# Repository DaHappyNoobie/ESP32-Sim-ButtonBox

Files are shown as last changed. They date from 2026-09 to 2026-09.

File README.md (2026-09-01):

## ESP32 Sim Buttonbox
I got into flying IL-2 Great Battles pretty recently, and found myself needing a lot of buttons for control surfaces trimming, engine controls, radiators, etc...
Not enough buttons on my stick and throttle, and using keyboard is annoying! I need a button box! Good opportunity for a small personal project and learning a bit about building devices in an enclosure like this.
Time to make a simple but usable USB button box.

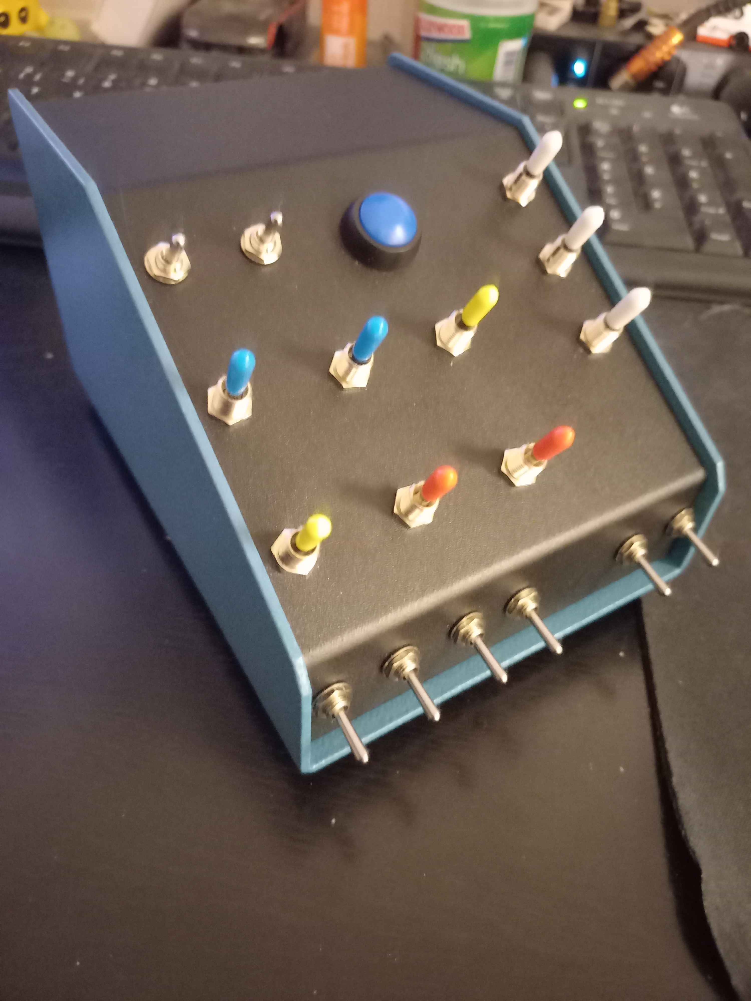
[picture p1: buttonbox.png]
Picture of the box


## What it does
This box exposes 9 bidirectional momentary switches, 8 toggle switches, and a button (27 GPIOs total). It uses an ESP32-S3 microcontroller implementing the TinyUSB stack with HID gamepad profile. This allows the box to be plug-and-play into any USB host, without the need for drivers. The circuit board and firmware are intended to be either reused as-is in other configurations, or expanded upon for more complex button boxes.

## Firmware
Written using ESP-IDF v5.5.1 framework. Install that either independently or through the VSCode extension, build,, flash, restart the board, and the USB controller should pop up in your PC's peripherals, ready to use.
The firmware itself is simple, derived from the TinyUSb HID example in ESP-IDF. A simple polling loop handles reading all the inputs, then building and sending a HID report through USB. Provisions are made in hardware to use the I/Os in Interrupt mode instead of polling (even through the I²C GPIO expander), but it's not really needed for my current use.
Keep the small Boot button pressed on the board while plugging the USB in to boot up in firmware download mode and reprogram the board if needed.

## Hardware
I designed a small 2-layer PCB implementing everything that's needed for a generic button box controller. Hook up your buttons and switches to the screw terminals on the board and start building.
The USB-B receptacle sticks out the back of the PCB, as it is intended to be mounted against the rear face of the enclosure.
I used a Hammond 1456CE3BKBU aluminium enclosure to build this project. It's relatively cheap, easy to work on, and has the perfect form factor for my space-constrained requirements.

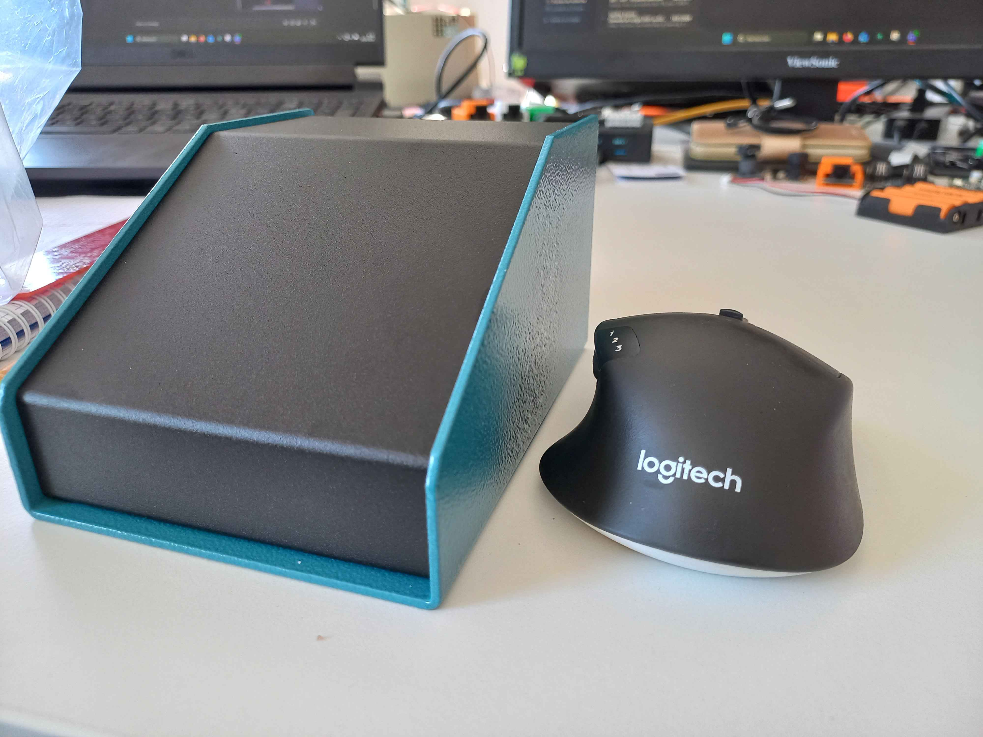
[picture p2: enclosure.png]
Bare enclosure

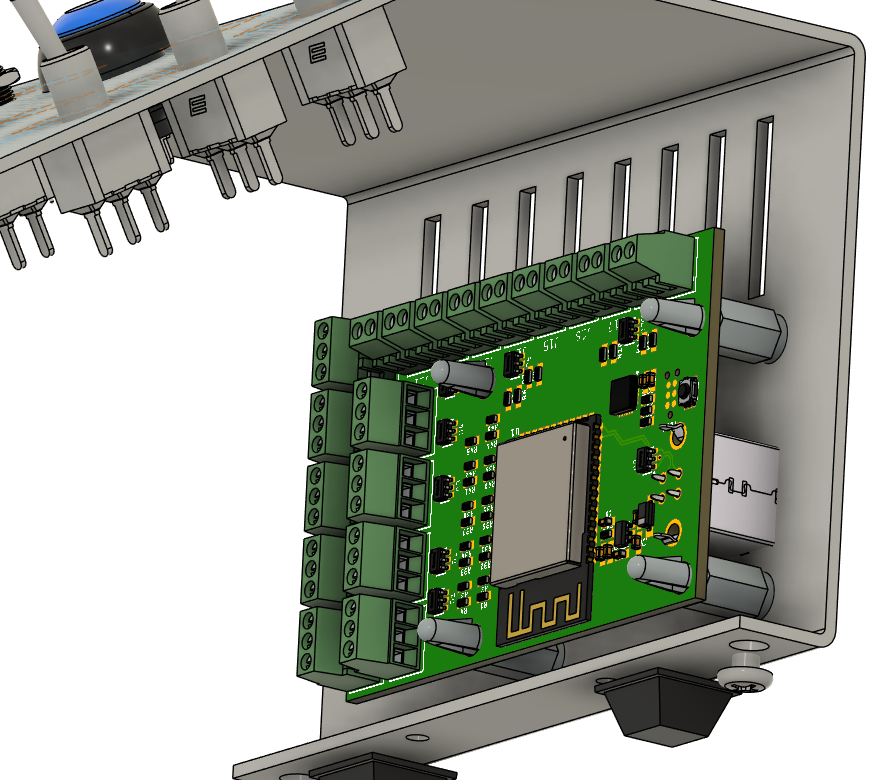
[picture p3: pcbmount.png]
PCB mount


MECHANICAL_ASSEMBLY folder contains 3D models in.step format for the following elements :
- Bare enclosure as sold
- Enclosure with the necessary drill holes for buttons, switches and mounting
- Controller circuit board
- Fully assembled button box (with all independent parts embedded in the file)

PCB_ESP32_SimButtonBox folder contains the circuit board design files :
- Parts BOM
- Autodesk EAGLE CAD files in .sch and .brd formats. Since EAGLE is now discontinued, you should be able to import them in Fusion360 Electronics with no issue. KiCAD should work too!
- Schematic in PDF format
- Gerber files for manufacturing the PCBs. I recommend getting a small solder stencil according to the Gerbers for easier reflow soldering.

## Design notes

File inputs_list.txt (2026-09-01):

List of button box inputs
-------------------------

Total : 
9 Momentary switches
8 Toggle switches
1 Buttons
-----> If using 9 momentaries, 8 toggles, 1 button -> 27 GPIOs
-----> At least 1 GPIO Expander (16bit) should be used

TRIMMING
--------
Elevator Trim / Stabilizer +/- -> Momentary switch
Aileron Trim +/- -> Momentary switch
Rudder Trim +/- -> Momentary switch

ENGINE CONTROL
--------------
Engine Select 1 On/Off -> Toggle switch (small)
Engine Select 2 On/Off -> Toggle switch (small)
Propeller Pitch / RPM +/- -> Momentary switch
Fuel Mixture +/- -> Momentary switch
Oil Radiator +/- -> Momentary switch
Water Radiator / Inlet cowl +/- -> Momentary switch
Outlet cowl +/- -> Momentary switch
Supercharger Gear +/- -> Momentary switch
Engine Ignition -> Button

GEAR AND LIGHTS
---------------
Landing Gear Up/Down -> Toggle switch
Tail Wheel Lock/Unlock -> Toggle switch
Landing Lights toggle -> Toggle switch
Formation Lights toggle -> Toggle switch

MISC
----
Bomber autopilot/autolevel -> Toggle switch

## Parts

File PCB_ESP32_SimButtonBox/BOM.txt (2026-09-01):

Partlist exported from C:/Users/HugoCuzon/Documents/Perso-3D/ESP32_SimButtonBox/ESP32_SimButtonBox_Controller.sch at 18/02/2026 12:15

Qty Value               Device                   Package                   Parts                                                                                                                                  Description                                               ALTERNATE APPLICATION BOM_CAT C-CH CHANNELS CROSS-REF CROSSREFS CURRENT DATASHEET-URL                                                 DESCRIPTION                                                               EQUIVALENCE GERDER     H     INTERFACE-TYPE IOUT  IPEAK IR-UL IR1  ISHDN MATERIAL MF                MOUNT MP                  NOT_IN_BOM OPERATION-FORCE PACKAGING PINS PITCH  POL POPULARITY POWER REF-EXCALIBUR REF_EXCALIBUR TOLERANCE TYPE       VALUE         VBR VMAX VMIN  VOLTAGE WIRE                                 WORKING-VOLTAGE WORKING-VOLTAGE-UL
9                       691210910002             691210910002              J11, J12, J13, J14, J15, J16, J17, J18, J19                                                                                            WR-TBL Serie 2109 - 2.54 mm Horiz. Entry                                                                                          https://www.we-online.com/catalog/datasheet/691210910002.pdf  WR-TBL Rising Cage Clamp                                                                                                          6A                        Wurth Elektronik  THT    691210910002                                             2   2.54mm                                                            Horizontal                                      30 to 18 (AWG) 0.0509 to 0.823 (mm²)                 150V (AC)         
9                       691210910003             691210910003              J2, J3, J4, J5, J6, J7, J8, J9, J10                                                                                                    WR-TBL Serie 2109 - 2.54 mm Horiz. Entry                                                                                          https://www.we-online.com/catalog/datasheet/691210910003.pdf  WR-TBL Rising Cage Clamp                                                                                                          6A                        Wurth Elektronik  THT    691210910003                                             3   2.54mm                                                            Horizontal                                      30 to 18 (AWG) 0.0509 to 0.823 (mm²)                 150V (AC)         
3   100nF               CAP_0603                 C0603                     C4, C7, C8                                                                                                                             Capacitor                                                                       C_SMD                                                                                                                                                                                                                                                              X5R/X7R                                                                                                                                                                                                  16V                                                                            
29  10k                 RES_0603                 R0603                     R1, R2, R3, R4, R5, R6, R7, R8, R9, R10, R11, R12, R13, R30, R31, R32, R33, R34, R35, R36, R37, R38, R39, R40, R41, R42, R43, R44, R45 Resistor                                                                        R_SMD                                                                                                                                                                                                                                                                                                                                                                        80                                           1%                                                                                                                               
1   1N5819HW            SCHOTTKY_SOD123          SOD123                    D9                                                                                                                                     Schottky Diode                                                                                                            1A                                                                    Schottky diode                                                                                                                                                                      1N5819HW                                                                                                                                                                                                                                               
4   1uF                 CAP_0603                 C0603                     C1, C2, C3, C6                                                                                                                         Capacitor                                                                       C_SMD                                                                                                                                                                                                                                                              X5R/X7R                                                                                                                                                                                                  16V                                                                            
2   4.7k                RES_0603                 R0603                     R28, R29                                                                                                                               Resistor                                                                        R_SMD                                                                                                                                                                                                                                                                                                                                                                        80                                           1%                                                                                                                               
1   435151014824        435151014824             435151014824              S1                                                                                                                                     WS-TASV SMT Tact Switch 3.0 x 2.6 mm with ground terminal                                                                         https://www.we-online.com/catalog/datasheet/435151014824 .pdf WS-TASV Switches - Tact Switches                                                                 1.4mm                                                      Wurth Elektronik        435151014824                   240g                                                                                                        435151014824                                                                                                
8   5Vdc                WE-TVS_SOT23-6L_82402304 WE-TVS_SOT23-6L           D1, D2, D3, D4, D5, D6, D7, D8                                                                                                         WE-TVS TVS Diode – Standard Series                                                      13pF  4                                   https://www.we-online.com/catalog/datasheet/82402304.pdf      WE-TVS TVS Diode                                                                                                            6A                              Wurth Elektronik  SMT   82402304                                                                                                                                   5Vdc          6V                                                                                            
1   61400413321         61400413321              61400413321               J1                                                                                                                                     WR-COM USB 2.0 Type B Vertical                                      USB 2.0                                                       https://www.we-online.com/catalog/datasheet/61400413321.pdf   WR-USB Input/Output USB connectors                                                    Receptacle       Type B                           1.5A                Wurth Elktronik   THT   61400413321                                    Tray       4                               03178                                 Vertical   61400413321                                                               30V(AC)                           
1   ESP32-S3-WROOM-1-N8 ESP32-S3-WROOM-1-N8      WROOM-1                   U1                                                                                                                                     Module Overview                                                                                                                                                                                 Modules multiprotocoles SMD Module, ESP32-S3, 8 MB SPI Flash, PCB Antenna                                                                                   Espressif Systems       ESP32-S3-WROOM-1-N8                                                                                                                                                                                                                                    
1   LDO_EN_SOT23-5      LDO_EN_SOT23-5           SOT23-5                   U2                                                                                                                                     LDO with Enable pin                                                                                                                                                                             LDO                                                                                                                   500mA                                 Texas Instruments       TLV75533PDBV*                                                                                                                                                5.5V 1.45V                                                                                
1   PCF8575RGE          PCF8575RGE               QFN50P400X400X100-25T210N U3                                                                                                                                     Texas Instruments PCF8575                                                                                                                                                                       16bit I2C IO Expander                                                                                                                                       Texas Instruments       PCF8575RGER                                                                                                                                                                                                                                            
1   TC2030-MCP-NL       TC2030-MCP-NL            TC2030-MCP-NL             TCB1                                                                                                                                   TAG-CONNECT ICSP Connector                                                                                                                                                                                                                                                                                                                                                                              true                                                                                                                                                                                                                               
1   dnm                 CAP_0603                 C0603                     C5                                                                                                                                     Capacitor                                                                       C_SMD                                                                                                                                                                                                                                                              X5R/X7R                                                                                                                                                                                                  16V

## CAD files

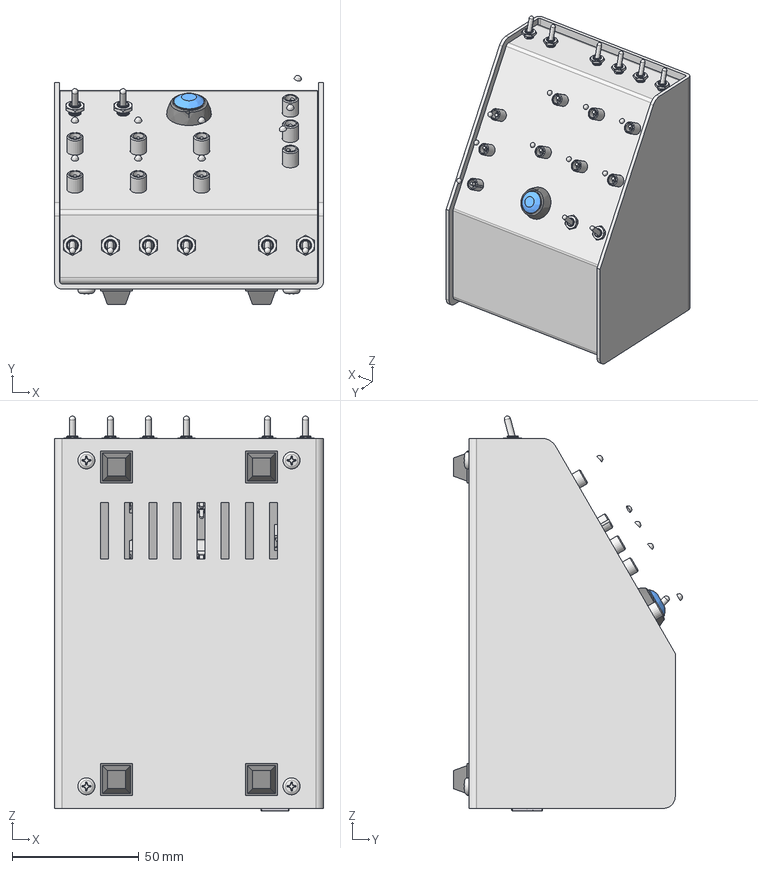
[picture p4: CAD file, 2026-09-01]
MECHANICAL_ASSEMBLY/ASSEMBLED_Buttonbox.step
106.2 x 90.4 x 155.8 mm
Taiway sub miniature switch spdt x 8
1456CE3 CASE
3M SJ-5018 RUBBER FOOT (PFR1421T3) x 4
Board
TC2030-MCP-NL
SOT23-5
C0201_20210301.STEP^C0201_20210301.STEP_Submodel-C0201_part_DesignRoo tModel_PCB_ESP32-S3-WROOM-1_V1(2)_PCB_ESP32-S3-WROOM-1_V1 x 14
L0201_20210301.STEP^L0201_20210301.STEP_Submodel-L0201_part_DesignRoo tModel_PCB_ESP32-S3-WROOM-1_V1(2)_PCB_ESP32-S3-WROOM-1_V1 x 3
C0402_20210301.STEP^C0402_20210301.STEP_Submodel-C0402_part_DesignRoo tModel_PCB_ESP32-S3-WROOM-1_V1(2)_PCB_ESP32-S3-WROOM-1_V1
R0201_20210301.STEP^R0201_20210301.STEP_Submodel-R0201_part_DesignRoo tModel_PCB_ESP32-S3-WROOM-1_V1(2)_PCB_ESP32-S3-WROOM-1_V1 x 8
trace_1^Submodel-MINI-ANT-TYPEB_668419613_part_DesignRootModel_PCB_ES P32-S3-WROOM-1_V1(2)_PCB_ESP32-S3-WROOM-1_V1
DFN1006.STEP^DFN1006.STEP_Submodel-SOD882_part_DesignRootModel_PCB_ES P32-S3-WROOM-1_V1(2)_PCB_ESP32-S3-WROOM-1_V1
SOP8_rev1_20210308.STEP^SOP8_rev1_20210308.STEP_Submodel-SOP8_1P27_6P 6_part_DesignRootModel_PCB_ESP32-S3-WROOM-1_V1(2)_PCB_ESP32-S3-WROOM-1 _V1
XTAL3225_20210301.STEP^XTAL3225_20210301.STEP_Submodel-XTAL3225_part_ DesignRootModel_PCB_ESP32-S3-WROOM-1_V1(2)_PCB_ESP32-S3-WROOM-1_V1
ESP32-S3_20210301.STEP^ESP32-S3_20210301.STEP_Submodel-QFN56_0P4_7_pa rt_DesignRootModel_PCB_ESP32-S3-WROOM-1_V1(2)_PCB_ESP32-S3-WROOM-1_V1
uid__4-128^DesignRootModel_PCB_ESP32-S3-WROOM-1_V1(2)_PCB_ESP32-S3-WR OOM-1_V1
uid__4-129^DesignRootModel_PCB_ESP32-S3-WROOM-1_V1(2)_PCB_ESP32-S3-WR OOM-1_V1
uid__4-130^DesignRootModel_PCB_ESP32-S3-WROOM-1_V1(2)_PCB_ESP32-S3-WR OOM-1_V1
uid__4-149^DesignRootModel_PCB_ESP32-S3-WROOM-1_V1(2)_PCB_ESP32-S3-WR OOM-1_V1
uid__4-150^DesignRootModel_PCB_ESP32-S3-WROOM-1_V1(2)_PCB_ESP32-S3-WR OOM-1_V1
uid__4-151^DesignRootModel_PCB_ESP32-S3-WROOM-1_V1(2)_PCB_ESP32-S3-WR OOM-1_V1
uid__4-167^DesignRootModel_PCB_ESP32-S3-WROOM-1_V1(2)_PCB_ESP32-S3-WR OOM-1_V1
uid__4-168^DesignRootModel_PCB_ESP32-S3-WROOM-1_V1(2)_PCB_ESP32-S3-WR OOM-1_V1
uid__4-169^DesignRootModel_PCB_ESP32-S3-WROOM-1_V1(2)_PCB_ESP32-S3-WR OOM-1_V1
uid__1-279^DesignRootModel_PCB_ESP32-S3-WROOM-1_V1(2)_PCB_ESP32-S3-WR OOM-1_V1
uid__1-280^DesignRootModel_PCB_ESP32-S3-WROOM-1_V1(2)_PCB_ESP32-S3-WR OOM-1_V1
uid__1-292^DesignRootModel_PCB_ESP32-S3-WROOM-1_V1(2)_PCB_ESP32-S3-WR OOM-1_V1
uid__1-298^DesignRootModel_PCB_ESP32-S3-WROOM-1_V1(2)_PCB_ESP32-S3-WR OOM-1_V1
uid__1-299^DesignRootModel_PCB_ESP32-S3-WROOM-1_V1(2)_PCB_ESP32-S3-WR OOM-1_V1
uid__1-300^DesignRootModel_PCB_ESP32-S3-WROOM-1_V1(2)_PCB_ESP32-S3-WR OOM-1_V1
uid__1-301^DesignRootModel_PCB_ESP32-S3-WROOM-1_V1(2)_PCB_ESP32-S3-WR OOM-1_V1
uid__1-304^DesignRootModel_PCB_ESP32-S3-WROOM-1_V1(2)_PCB_ESP32-S3-WR OOM-1_V1
uid__1-305^DesignRootModel_PCB_ESP32-S3-WROOM-1_V1(2)_PCB_ESP32-S3-WR OOM-1_V1
uid__1-308^DesignRootModel_PCB_ESP32-S3-WROOM-1_V1(2)_PCB_ESP32-S3-WR OOM-1_V1
uid__1-310^DesignRootModel_PCB_ESP32-S3-WROOM-1_V1(2)_PCB_ESP32-S3-WR OOM-1_V1
uid__1-311^DesignRootModel_PCB_ESP32-S3-WROOM-1_V1(2)_PCB_ESP32-S3-WR OOM-1_V1
uid__1-325^DesignRootModel_PCB_ESP32-S3-WROOM-1_V1(2)_PCB_ESP32-S3-WR OOM-1_V1
uid__1-334^DesignRootModel_PCB_ESP32-S3-WROOM-1_V1(2)_PCB_ESP32-S3-WR OOM-1_V1
uid__1-338^DesignRootModel_PCB_ESP32-S3-WROOM-1_V1(2)_PCB_ESP32-S3-WR OOM-1_V1
uid__1-339^DesignRootModel_PCB_ESP32-S3-WROOM-1_V1(2)_PCB_ESP32-S3-WR OOM-1_V1
uid__1-340^DesignRootModel_PCB_ESP32-S3-WROOM-1_V1(2)_PCB_ESP32-S3-WR OOM-1_V1
uid__1-343^DesignRootModel_PCB_ESP32-S3-WROOM-1_V1(2)_PCB_ESP32-S3-WR OOM-1_V1
uid__1-344^DesignRootModel_PCB_ESP32-S3-WROOM-1_V1(2)_PCB_ESP32-S3-WR OOM-1_V1
uid__1-345^DesignRootModel_PCB_ESP32-S3-WROOM-1_V1(2)_PCB_ESP32-S3-WR OOM-1_V1
uid__1-352^DesignRootModel_PCB_ESP32-S3-WROOM-1_V1(2)_PCB_ESP32-S3-WR OOM-1_V1
uid__1-354^DesignRootModel_PCB_ESP32-S3-WROOM-1_V1(2)_PCB_ESP32-S3-WR OOM-1_V1
uid__1-355^DesignRootModel_PCB_ESP32-S3-WROOM-1_V1(2)_PCB_ESP32-S3-WR OOM-1_V1
uid__1-357^DesignRootModel_PCB_ESP32-S3-WROOM-1_V1(2)_PCB_ESP32-S3-WR OOM-1_V1
uid__1-358^DesignRootModel_PCB_ESP32-S3-WROOM-1_V1(2)_PCB_ESP32-S3-WR OOM-1_V1
uid__1-359^DesignRootModel_PCB_ESP32-S3-WROOM-1_V1(2)_PCB_ESP32-S3-WR OOM-1_V1
uid__1-364^DesignRootModel_PCB_ESP32-S3-WROOM-1_V1(2)_PCB_ESP32-S3-WR OOM-1_V1
uid__1-365^DesignRootModel_PCB_ESP32-S3-WROOM-1_V1(2)_PCB_ESP32-S3-WR OOM-1_V1
uid__1-371^DesignRootModel_PCB_ESP32-S3-WROOM-1_V1(2)_PCB_ESP32-S3-WR OOM-1_V1
uid__1-375^DesignRootModel_PCB_ESP32-S3-WROOM-1_V1(2)_PCB_ESP32-S3-WR OOM-1_V1
uid__1-376^DesignRootModel_PCB_ESP32-S3-WROOM-1_V1(2)_PCB_ESP32-S3-WR OOM-1_V1
uid__1-378^DesignRootModel_PCB_ESP32-S3-WROOM-1_V1(2)_PCB_ESP32-S3-WR OOM-1_V1
uid__1-379^DesignRootModel_PCB_ESP32-S3-WROOM-1_V1(2)_PCB_ESP32-S3-WR OOM-1_V1
uid__1-380^DesignRootModel_PCB_ESP32-S3-WROOM-1_V1(2)_PCB_ESP32-S3-WR OOM-1_V1
uid__1-381^DesignRootModel_PCB_ESP32-S3-WROOM-1_V1(2)_PCB_ESP32-S3-WR OOM-1_V1
uid__1-382^DesignRootModel_PCB_ESP32-S3-WROOM-1_V1(2)_PCB_ESP32-S3-WR OOM-1_V1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

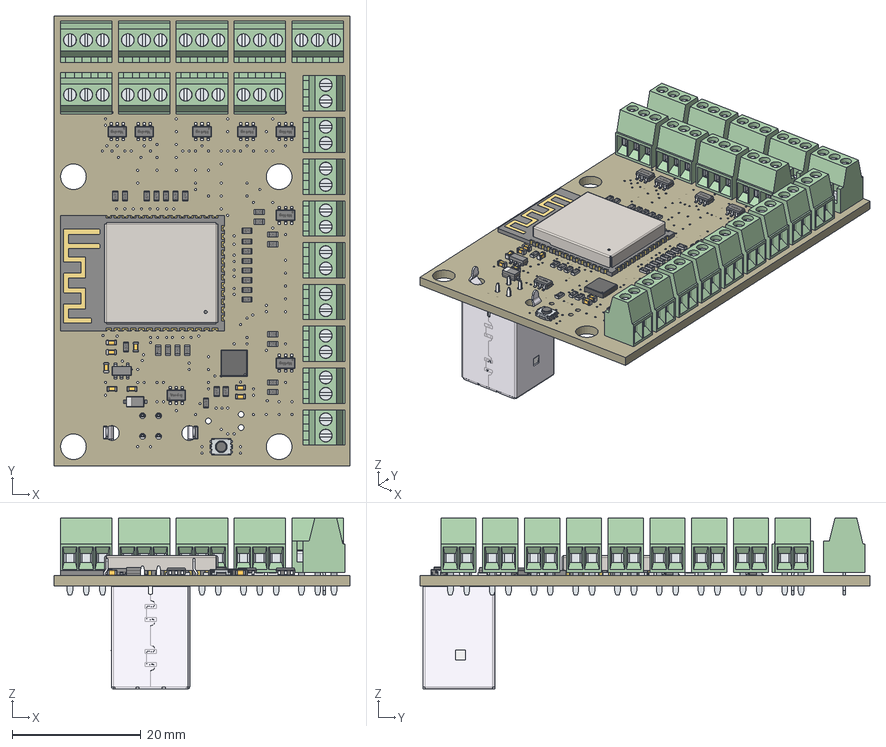
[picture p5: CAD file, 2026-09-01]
MECHANICAL_ASSEMBLY/3DPCB_ESP32_SimButtonBox_Controller.step
46.0 x 70.0 x 26.6 mm
Board
TC2030-MCP-NL
SOT23-5
C0201_20210301.STEP^C0201_20210301.STEP_Submodel-C0201_part_DesignRoo tModel_PCB_ESP32-S3-WROOM-1_V1(2)_PCB_ESP32-S3-WROOM-1_V1 x 14
L0201_20210301.STEP^L0201_20210301.STEP_Submodel-L0201_part_DesignRoo tModel_PCB_ESP32-S3-WROOM-1_V1(2)_PCB_ESP32-S3-WROOM-1_V1 x 3
C0402_20210301.STEP^C0402_20210301.STEP_Submodel-C0402_part_DesignRoo tModel_PCB_ESP32-S3-WROOM-1_V1(2)_PCB_ESP32-S3-WROOM-1_V1
R0201_20210301.STEP^R0201_20210301.STEP_Submodel-R0201_part_DesignRoo tModel_PCB_ESP32-S3-WROOM-1_V1(2)_PCB_ESP32-S3-WROOM-1_V1 x 8
trace_1^Submodel-MINI-ANT-TYPEB_668419613_part_DesignRootModel_PCB_ES P32-S3-WROOM-1_V1(2)_PCB_ESP32-S3-WROOM-1_V1
DFN1006.STEP^DFN1006.STEP_Submodel-SOD882_part_DesignRootModel_PCB_ES P32-S3-WROOM-1_V1(2)_PCB_ESP32-S3-WROOM-1_V1
SOP8_rev1_20210308.STEP^SOP8_rev1_20210308.STEP_Submodel-SOP8_1P27_6P 6_part_DesignRootModel_PCB_ESP32-S3-WROOM-1_V1(2)_PCB_ESP32-S3-WROOM-1 _V1
XTAL3225_20210301.STEP^XTAL3225_20210301.STEP_Submodel-XTAL3225_part_ DesignRootModel_PCB_ESP32-S3-WROOM-1_V1(2)_PCB_ESP32-S3-WROOM-1_V1
ESP32-S3_20210301.STEP^ESP32-S3_20210301.STEP_Submodel-QFN56_0P4_7_pa rt_DesignRootModel_PCB_ESP32-S3-WROOM-1_V1(2)_PCB_ESP32-S3-WROOM-1_V1
uid__4-128^DesignRootModel_PCB_ESP32-S3-WROOM-1_V1(2)_PCB_ESP32-S3-WR OOM-1_V1
uid__4-129^DesignRootModel_PCB_ESP32-S3-WROOM-1_V1(2)_PCB_ESP32-S3-WR OOM-1_V1
uid__4-130^DesignRootModel_PCB_ESP32-S3-WROOM-1_V1(2)_PCB_ESP32-S3-WR OOM-1_V1
uid__4-149^DesignRootModel_PCB_ESP32-S3-WROOM-1_V1(2)_PCB_ESP32-S3-WR OOM-1_V1
uid__4-150^DesignRootModel_PCB_ESP32-S3-WROOM-1_V1(2)_PCB_ESP32-S3-WR OOM-1_V1
uid__4-151^DesignRootModel_PCB_ESP32-S3-WROOM-1_V1(2)_PCB_ESP32-S3-WR OOM-1_V1
uid__4-167^DesignRootModel_PCB_ESP32-S3-WROOM-1_V1(2)_PCB_ESP32-S3-WR OOM-1_V1
uid__4-168^DesignRootModel_PCB_ESP32-S3-WROOM-1_V1(2)_PCB_ESP32-S3-WR OOM-1_V1
uid__4-169^DesignRootModel_PCB_ESP32-S3-WROOM-1_V1(2)_PCB_ESP32-S3-WR OOM-1_V1
uid__1-279^DesignRootModel_PCB_ESP32-S3-WROOM-1_V1(2)_PCB_ESP32-S3-WR OOM-1_V1
uid__1-280^DesignRootModel_PCB_ESP32-S3-WROOM-1_V1(2)_PCB_ESP32-S3-WR OOM-1_V1
uid__1-292^DesignRootModel_PCB_ESP32-S3-WROOM-1_V1(2)_PCB_ESP32-S3-WR OOM-1_V1
uid__1-298^DesignRootModel_PCB_ESP32-S3-WROOM-1_V1(2)_PCB_ESP32-S3-WR OOM-1_V1
uid__1-299^DesignRootModel_PCB_ESP32-S3-WROOM-1_V1(2)_PCB_ESP32-S3-WR OOM-1_V1
uid__1-300^DesignRootModel_PCB_ESP32-S3-WROOM-1_V1(2)_PCB_ESP32-S3-WR OOM-1_V1
uid__1-301^DesignRootModel_PCB_ESP32-S3-WROOM-1_V1(2)_PCB_ESP32-S3-WR OOM-1_V1
uid__1-304^DesignRootModel_PCB_ESP32-S3-WROOM-1_V1(2)_PCB_ESP32-S3-WR OOM-1_V1
uid__1-305^DesignRootModel_PCB_ESP32-S3-WROOM-1_V1(2)_PCB_ESP32-S3-WR OOM-1_V1
uid__1-308^DesignRootModel_PCB_ESP32-S3-WROOM-1_V1(2)_PCB_ESP32-S3-WR OOM-1_V1
uid__1-310^DesignRootModel_PCB_ESP32-S3-WROOM-1_V1(2)_PCB_ESP32-S3-WR OOM-1_V1
uid__1-311^DesignRootModel_PCB_ESP32-S3-WROOM-1_V1(2)_PCB_ESP32-S3-WR OOM-1_V1
uid__1-325^DesignRootModel_PCB_ESP32-S3-WROOM-1_V1(2)_PCB_ESP32-S3-WR OOM-1_V1
uid__1-334^DesignRootModel_PCB_ESP32-S3-WROOM-1_V1(2)_PCB_ESP32-S3-WR OOM-1_V1
uid__1-338^DesignRootModel_PCB_ESP32-S3-WROOM-1_V1(2)_PCB_ESP32-S3-WR OOM-1_V1
uid__1-339^DesignRootModel_PCB_ESP32-S3-WROOM-1_V1(2)_PCB_ESP32-S3-WR OOM-1_V1
uid__1-340^DesignRootModel_PCB_ESP32-S3-WROOM-1_V1(2)_PCB_ESP32-S3-WR OOM-1_V1
uid__1-343^DesignRootModel_PCB_ESP32-S3-WROOM-1_V1(2)_PCB_ESP32-S3-WR OOM-1_V1
uid__1-344^DesignRootModel_PCB_ESP32-S3-WROOM-1_V1(2)_PCB_ESP32-S3-WR OOM-1_V1
uid__1-345^DesignRootModel_PCB_ESP32-S3-WROOM-1_V1(2)_PCB_ESP32-S3-WR OOM-1_V1
uid__1-352^DesignRootModel_PCB_ESP32-S3-WROOM-1_V1(2)_PCB_ESP32-S3-WR OOM-1_V1
uid__1-354^DesignRootModel_PCB_ESP32-S3-WROOM-1_V1(2)_PCB_ESP32-S3-WR OOM-1_V1
uid__1-355^DesignRootModel_PCB_ESP32-S3-WROOM-1_V1(2)_PCB_ESP32-S3-WR OOM-1_V1
uid__1-357^DesignRootModel_PCB_ESP32-S3-WROOM-1_V1(2)_PCB_ESP32-S3-WR OOM-1_V1
uid__1-358^DesignRootModel_PCB_ESP32-S3-WROOM-1_V1(2)_PCB_ESP32-S3-WR OOM-1_V1
uid__1-359^DesignRootModel_PCB_ESP32-S3-WROOM-1_V1(2)_PCB_ESP32-S3-WR OOM-1_V1
uid__1-364^DesignRootModel_PCB_ESP32-S3-WROOM-1_V1(2)_PCB_ESP32-S3-WR OOM-1_V1
uid__1-365^DesignRootModel_PCB_ESP32-S3-WROOM-1_V1(2)_PCB_ESP32-S3-WR OOM-1_V1
uid__1-371^DesignRootModel_PCB_ESP32-S3-WROOM-1_V1(2)_PCB_ESP32-S3-WR OOM-1_V1
uid__1-375^DesignRootModel_PCB_ESP32-S3-WROOM-1_V1(2)_PCB_ESP32-S3-WR OOM-1_V1
uid__1-376^DesignRootModel_PCB_ESP32-S3-WROOM-1_V1(2)_PCB_ESP32-S3-WR OOM-1_V1
uid__1-378^DesignRootModel_PCB_ESP32-S3-WROOM-1_V1(2)_PCB_ESP32-S3-WR OOM-1_V1
uid__1-379^DesignRootModel_PCB_ESP32-S3-WROOM-1_V1(2)_PCB_ESP32-S3-WR OOM-1_V1
uid__1-380^DesignRootModel_PCB_ESP32-S3-WROOM-1_V1(2)_PCB_ESP32-S3-WR OOM-1_V1
uid__1-381^DesignRootModel_PCB_ESP32-S3-WROOM-1_V1(2)_PCB_ESP32-S3-WR OOM-1_V1
uid__1-382^DesignRootModel_PCB_ESP32-S3-WROOM-1_V1(2)_PCB_ESP32-S3-WR OOM-1_V1
uid__1-383^DesignRootModel_PCB_ESP32-S3-WROOM-1_V1(2)_PCB_ESP32-S3-WR OOM-1_V1
uid__1-384^DesignRootModel_PCB_ESP32-S3-WROOM-1_V1(2)_PCB_ESP32-S3-WR OOM-1_V1
uid__1-385^DesignRootModel_PCB_ESP32-S3-WROOM-1_V1(2)_PCB_ESP32-S3-WR OOM-1_V1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

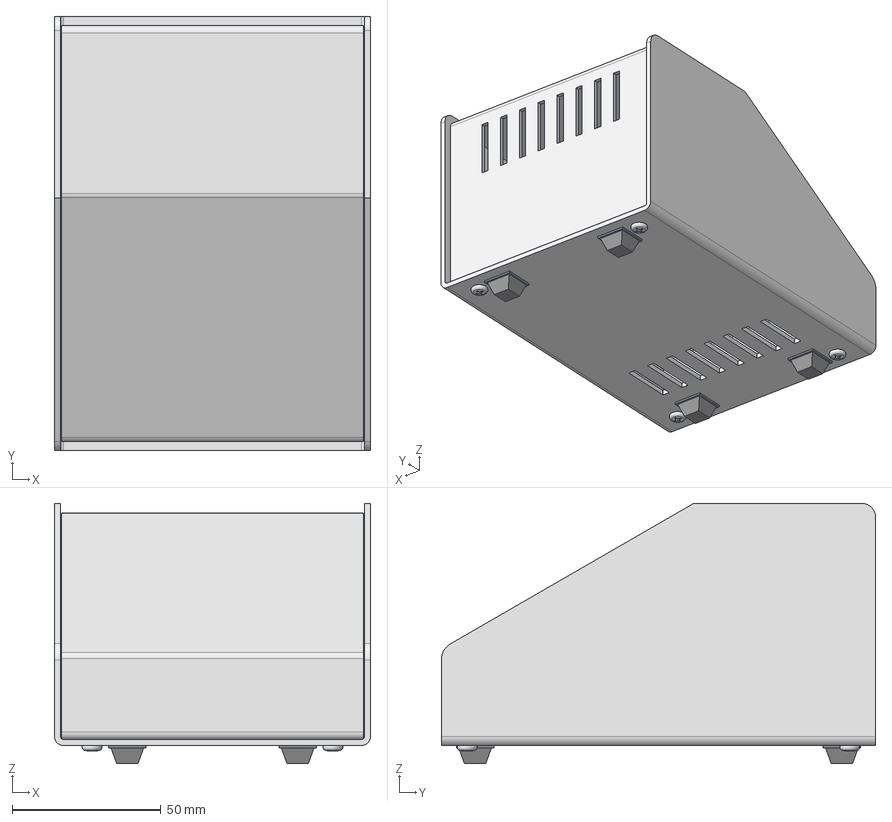
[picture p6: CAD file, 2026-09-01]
MECHANICAL_ASSEMBLY/Hammond_1456CE3BKBU.step
106.2 x 146.1 x 87.5 mm
1456CE3 CASE
1456CE3 TOP
3M SJ-5018 RUBBER FOOT (PFR1421T3) x 4

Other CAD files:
MECHANICAL_ASSEMBLY/1456CE3BKBU_Drilled.step

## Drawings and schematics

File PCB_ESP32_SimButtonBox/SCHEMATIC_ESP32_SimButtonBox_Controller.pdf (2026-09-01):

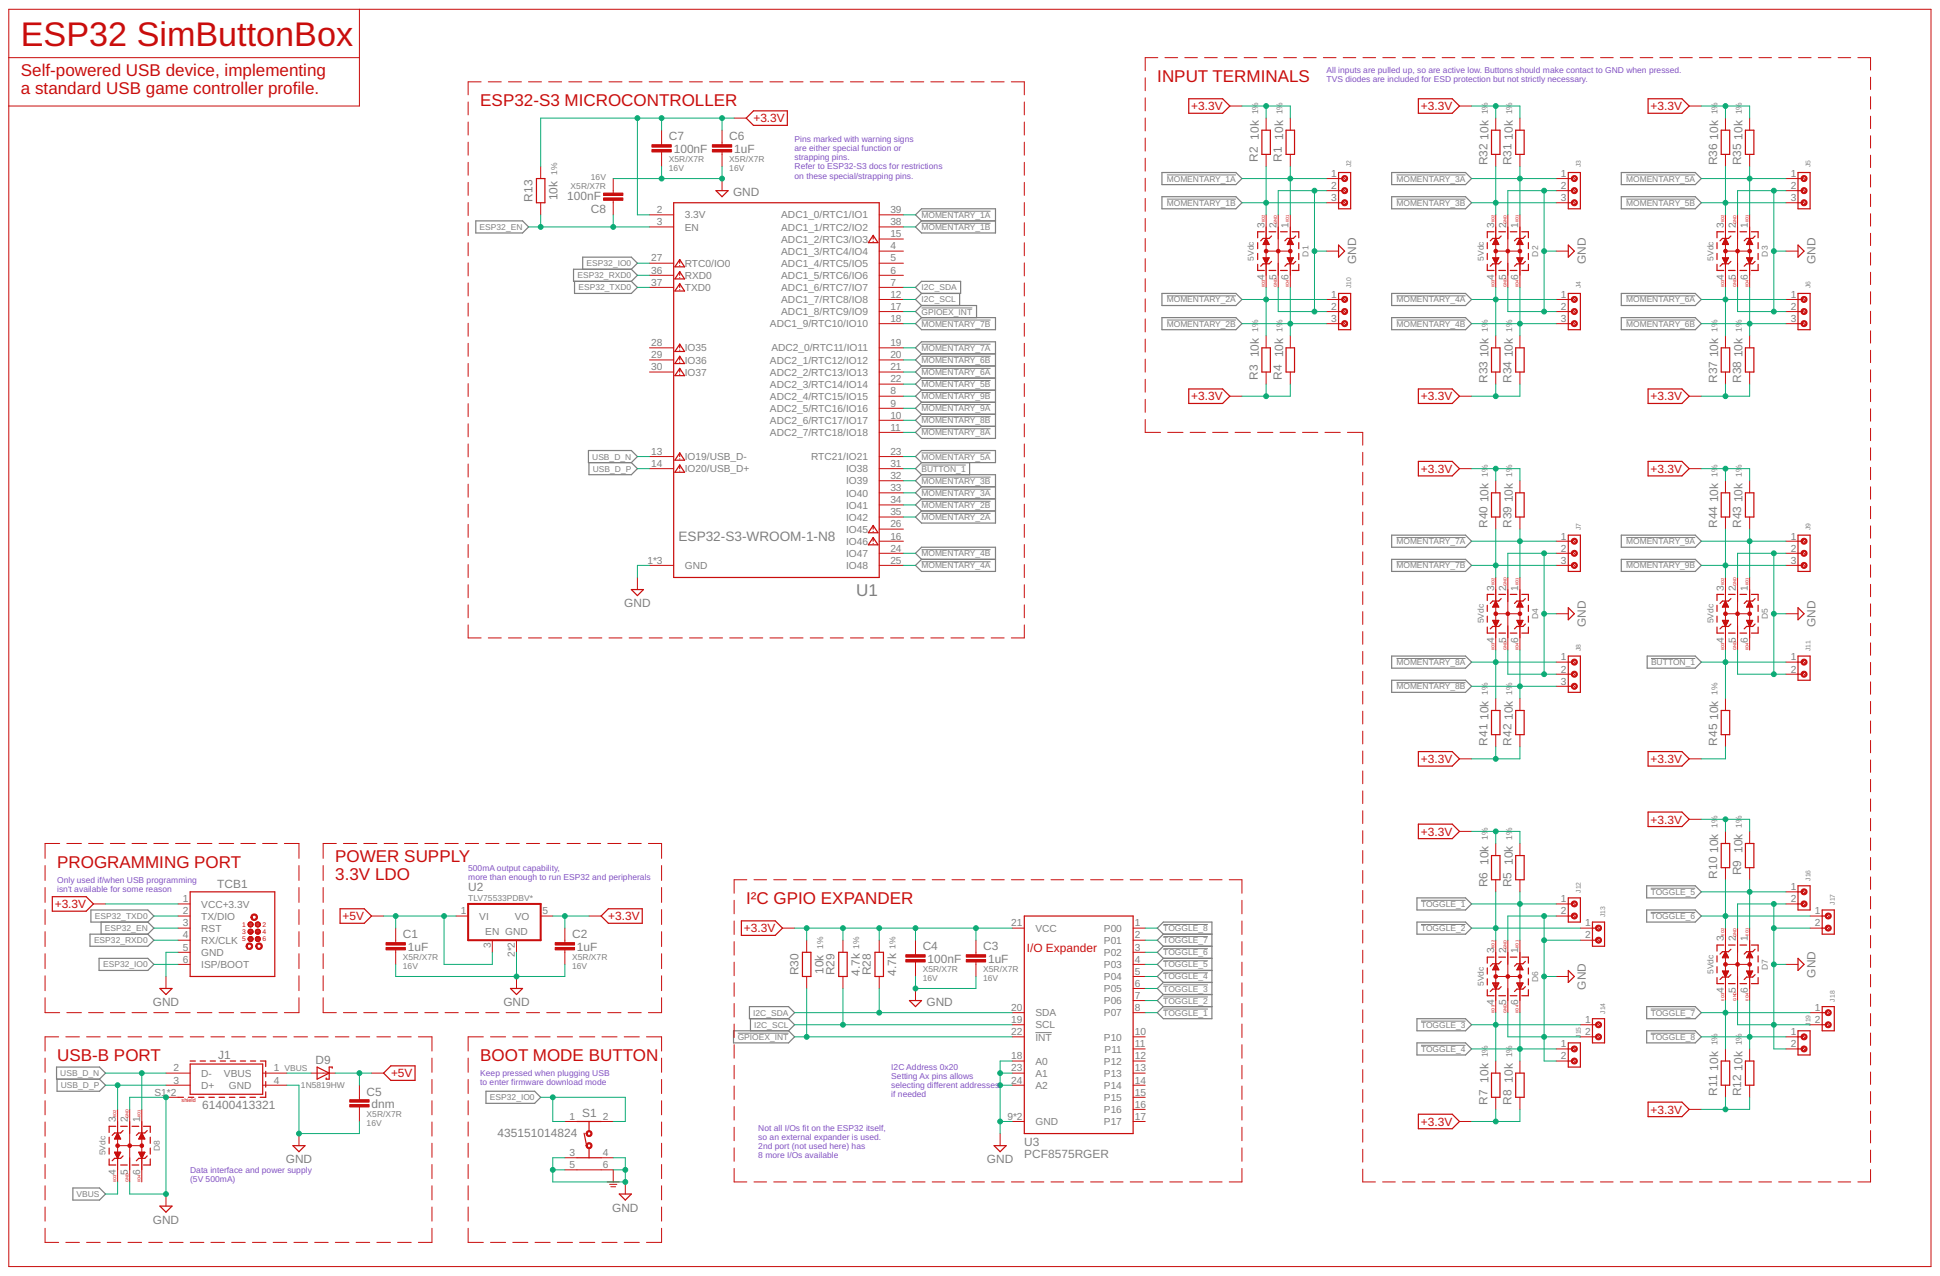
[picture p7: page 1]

Self-powered USB device, implementing
a standard USB game controller profile.

All inputs are pulled up, so are active low. Buttons should make contact to GND when pressed. TVS diodes are included for ESD protection but not strictly necessary.

Pins marked with warning signs are either special function or strapping pins. Refer to ESP32-S3 docs for restrictions on these special/strapping pins.

isn't available for some reason

I2C Address 0x20 Setting Ax pins allows

Keep pressed when plugging USB
to enter firmware download mode

Not all I/Os fit on the ESP32 itself, so an external expander is used. 2nd port (not used here) has 8 more I/Os available

Data interface and power supply

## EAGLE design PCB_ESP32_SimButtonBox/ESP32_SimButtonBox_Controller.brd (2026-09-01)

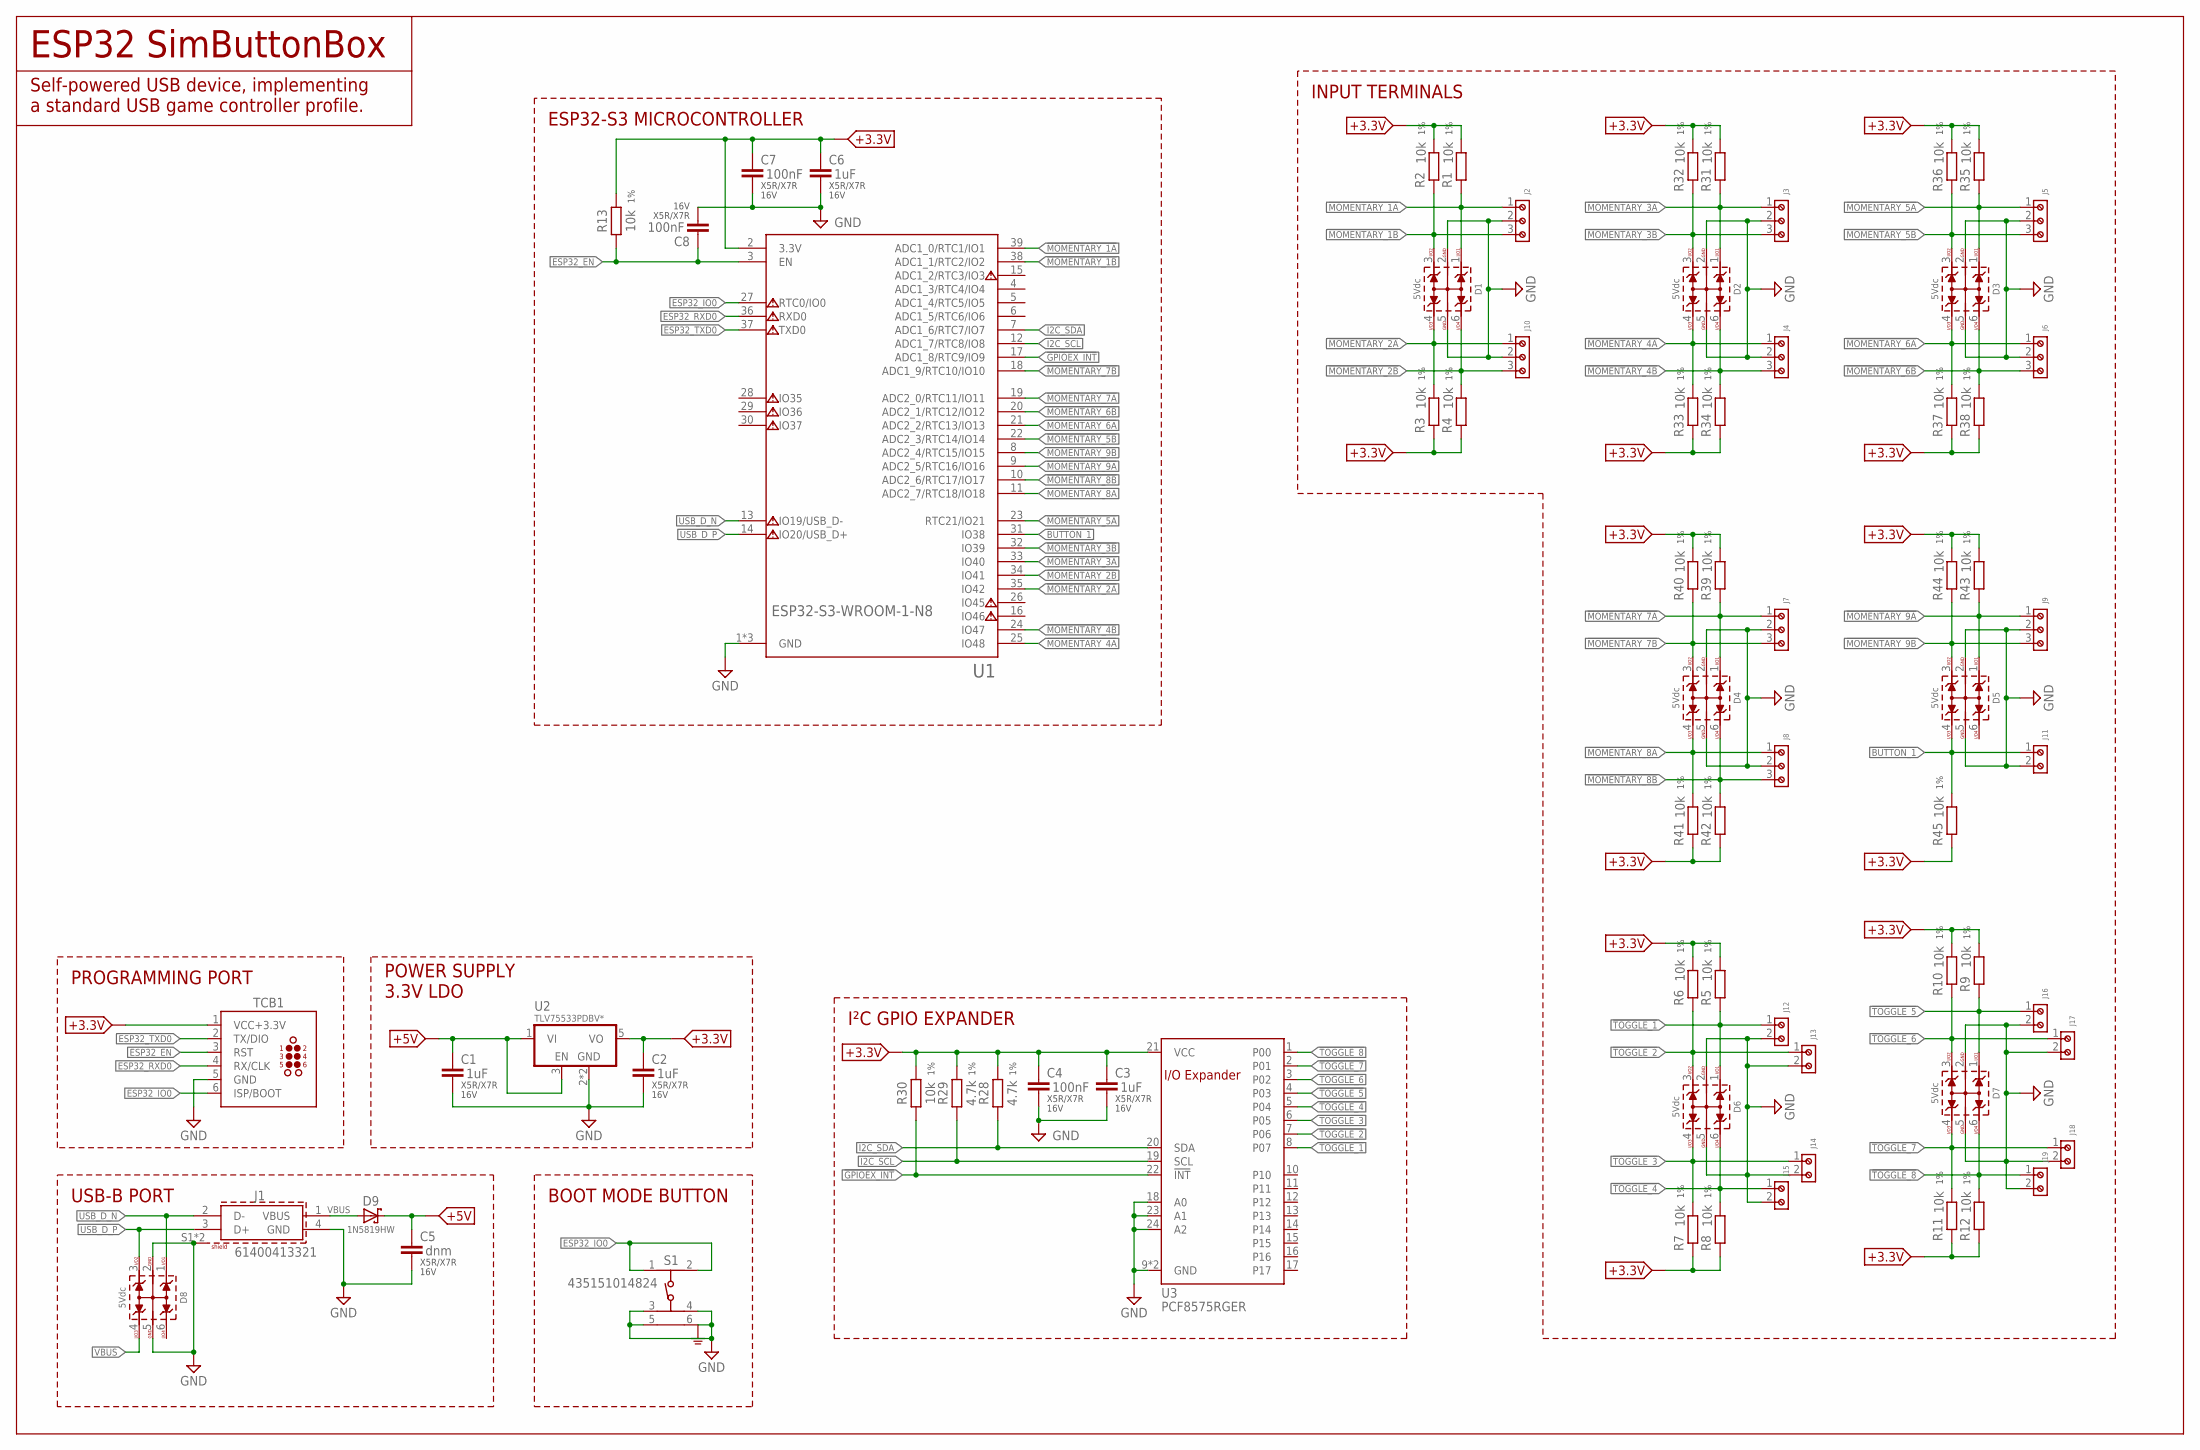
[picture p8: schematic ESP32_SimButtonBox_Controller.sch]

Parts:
C1, C2, C3, C6: 1uF; C0603; VOLTAGE 16V
C4, C7, C8: 100nF; C0603; VOLTAGE 16V
C5: dnm; C0603; VOLTAGE 16V
D1, D2, D3, D4, D5, D6, D7, D8: 5Vdc; WE-TVS_SOT23-6L
D9: 1N5819HW; SOD123
J1: 61400413321
J2, J3, J4, J5, J6, J7, J8, J9, J10: 691210910003
J11, J12, J13, J14, J15, J16, J17, J18, J19: 691210910002
R1, R2, R3, R4, R5, R6, R7, R8, R9, R10, R11, R12, R13, R30, R31, R32, R33, R34, R35, R36, R37, R38, R39, R40, R41, R42, R43, R44, R45: 10k; R0603
R28, R29: 4.7k; R0603
S1: 435151014824
TCB1: TC2030-MCP-NL
U1: ESP32-S3-WROOM-1-N8; WROOM-1
U2: LDO_EN_SOT23-5; SOT23-5
U3: PCF8575RGE; QFN50P400X400X100-25T210N

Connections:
!BUTTON_1: D5.4 (3), J11.1, R45.2, U1.31 (IO38)
!GPIOEX_INT: R30.1, U1.17 (ADC1_8/RTC9/IO9), U3.22 (!INT)
!MOMENTARY_1A: D1.1, J2.1, R1.1, U1.39 (ADC1_0/RTC1/IO1)
!MOMENTARY_1B: D1.3 (2), J2.3, R2.1, U1.38 (ADC1_1/RTC2/IO2)
!MOMENTARY_2A: D1.4 (3), J10.1, R3.2, U1.35 (IO42)
!MOMENTARY_2B: D1.6 (4), J10.3, R4.2, U1.34 (IO41)
!MOMENTARY_3A: D2.1, J3.1, R31.1, U1.33 (IO40)
!MOMENTARY_3B: D2.3 (2), J3.3, R32.1, U1.32 (IO39)
!MOMENTARY_4A: D2.4 (3), J4.1, R33.2, U1.25 (IO48)
!MOMENTARY_4B: D2.6 (4), J4.3, R34.2, U1.24 (IO47)
!MOMENTARY_5A: D3.1, J5.1, R35.1, U1.23 (RTC21/IO21)
!MOMENTARY_5B: D3.3 (2), J5.3, R36.1, U1.22 (ADC2_3/RTC14/IO14)
!MOMENTARY_6A: D3.4 (3), J6.1, R37.2, U1.21 (ADC2_2/RTC13/IO13)
!MOMENTARY_6B: D3.6 (4), J6.3, R38.2, U1.20 (ADC2_1/RTC12/IO12)
!MOMENTARY_7A: D4.1, J7.1, R39.1, U1.19 (ADC2_0/RTC11/IO11)
!MOMENTARY_7B: D4.3 (2), J7.3, R40.1, U1.18 (ADC1_9/RTC10/IO10)
!MOMENTARY_8A: D4.4 (3), J8.1, R41.2, U1.11 (ADC2_7/RTC18/IO18)
!MOMENTARY_8B: D4.6 (4), J8.3, R42.2, U1.10 (ADC2_6/RTC17/IO17)
!MOMENTARY_9A: D5.1, J9.1, R43.1, U1.9 (ADC2_5/RTC16/IO16)
!MOMENTARY_9B: D5.3 (2), J9.3, R44.1, U1.8 (ADC2_4/RTC15/IO15)
!TOGGLE_1: D6.1, J12.1, R5.1, U3.8 (P07)
!TOGGLE_2: D6.3 (2), J13.1, R6.1, U3.7 (P06)
!TOGGLE_3: D6.4 (3), J14.1, R7.2, U3.6 (P05)
!TOGGLE_4: D6.6 (4), J15.1, R8.2, U3.5 (P04)
!TOGGLE_5: D7.1, J16.1, R9.1, U3.4 (P03)
!TOGGLE_6: D7.3 (2), J17.1, R10.1, U3.3 (P02)
!TOGGLE_7: D7.4 (3), J18.1, R11.2, U3.2 (P01)
!TOGGLE_8: D7.6 (4), J19.1, R12.2, U3.1 (P00)
+3.3V: C2.1, C3.1, C4.1, C6.1, C7.1, R1.2, R2.2, R3.1, R4.1, R5.2, R6.2, R7.1, R8.1, R9.2, R10.2, R11.1, R12.1, R13.2, R28.2, R29.2, R30.2, R31.2, R32.2, R33.1, R34.1, R35.2, R36.2, R37.1, R38.1, R39.2, R40.2, R41.1, R42.1, R43.2, R44.2, R45.1, TCB1.1 (VCC+3.3V), U1.2 (3.3V), U2.5 (VO), U3.21 (VCC)
+5V: C1.1, C5.1, D9.C, U2.1 (VI), U2.3 (EN)
ESP32_EN: C8.1, R13.1, TCB1.3 (RST), U1.3 (EN)
ESP32_IO0: S1.1, S1.2, TCB1.6 (ISP/BOOT), U1.27 (RTC0/IO0)
ESP32_RXD0: TCB1.4 (RX/CLK), U1.36 (RXD0)
ESP32_TXD0: TCB1.2 (TX/DIO), U1.37 (TXD0)
GND: C1.2, C2.2, C3.2, C4.2, C5.2, C6.2, C7.2, C8.2, D1.2 (GND), D1.5 (GND), D2.2 (GND), D2.5 (GND), D3.2 (GND), D3.5 (GND), D4.2 (GND), D4.5 (GND), D5.2 (GND), D5.5 (GND), D6.2 (GND), D6.5 (GND), D7.2 (GND), D7.5 (GND), D8.2 (GND), D8.5 (GND), J1.4 (GND), J1.S1 (SHIELD), J1.S2 (SHIELD), J2.2, J3.2, J4.2, J5.2, J6.2, J7.2, J8.2, J9.2, J10.2, J11.2, J12.2, J13.2, J14.2, J15.2, J16.2, J17.2, J18.2, J19.2, S1.3, S1.4, S1.5, S1.6, TCB1.5 (GND), U1.1 (GND), U1.40 (GND), U1.P$1 (GND), U2.2 (GND), U2.4 (GND), U3.9 (GND), U3.18 (A0), U3.23 (A1), U3.24 (A2), U3.25 (GND)
I2C_SCL: R29.1, U1.12 (ADC1_7/RTC8/IO8), U3.19 (SCL)
I2C_SDA: R28.1, U1.7 (ADC1_6/RTC7/IO7), U3.20 (SDA)
USB_D_N: D8.1, J1.2 (D-), U1.13 (IO19/USB_D-)
USB_D_P: D8.3 (2), J1.3 (D+), U1.14 (IO20/USB_D+)
VBUS: D8.4 (3), D9.A, J1.1 (VBUS)

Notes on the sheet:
ESP32-S3 MICROCONTROLLER
PROGRAMMING PORT
POWER SUPPLY 3.3V LDO
I²C GPIO EXPANDER
USB-B PORT
BOOT MODE BUTTON
INPUT TERMINALS
ESP32 SimButtonBox
Self-powered USB device, implementing a standard USB game controller profile.

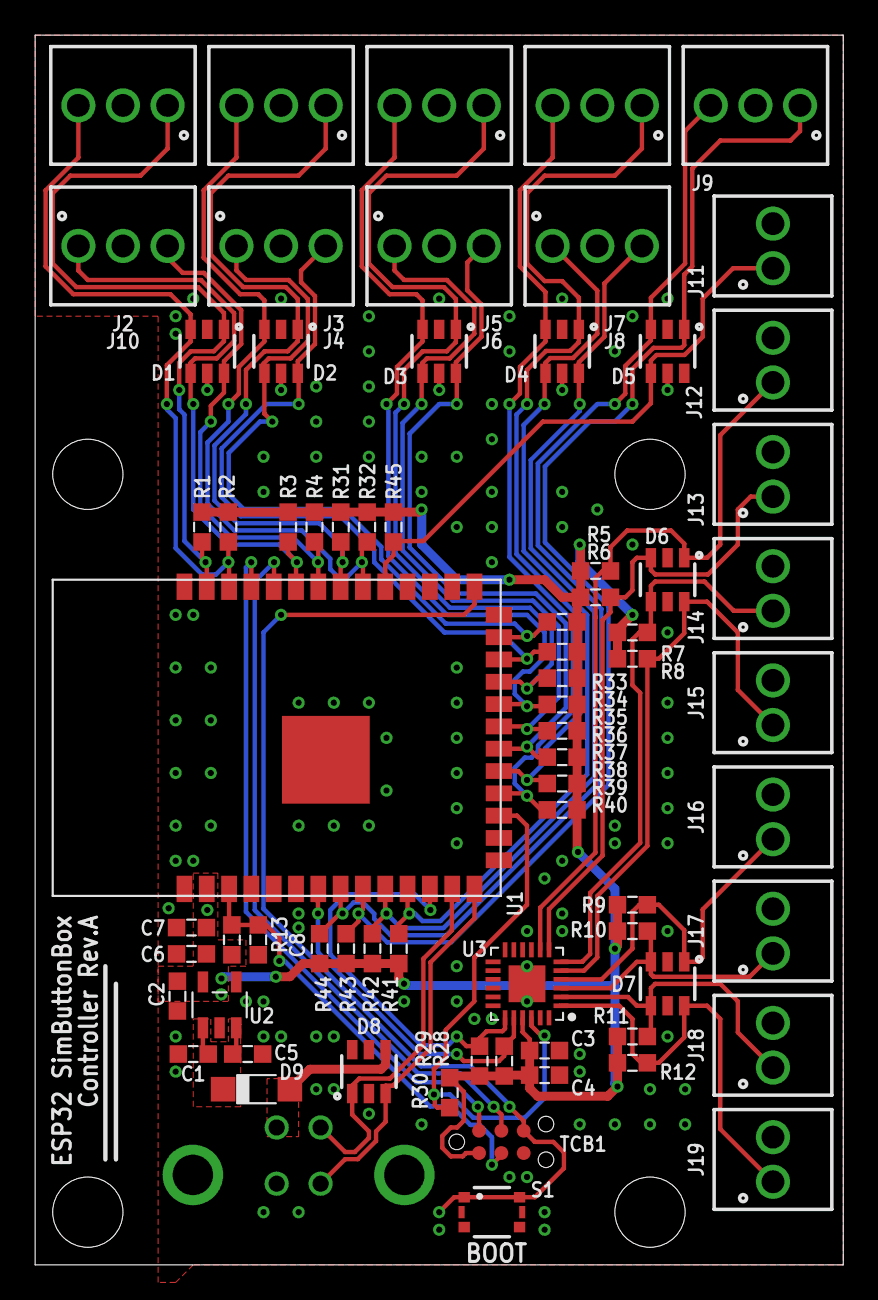
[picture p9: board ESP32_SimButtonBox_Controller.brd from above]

Board: 2 copper layers, 46.0 x 70.0 mm, 73 parts (1 on the bottom side), 40 nets.

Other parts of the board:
U$1: PCB-SPEC

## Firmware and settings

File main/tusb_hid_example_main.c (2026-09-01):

////////
//  ESP32 Sim Buttonbox - by DaHappyNoobie
//  Based on the tinyUSB USB HID example code from ESP-IDF.
//  This code instantiates a USB-HID gamepad profile from the TinyUSB stack, so that the ESP32-S3 shows up as a driverless game controller on PC.
//  GPIOs are used both directly on-chip as well as through a I²C GPIO expander for additional inputs.
//  Everything is handled as a simple sequential loop, as the use case here doesn't need high speed input reading and reporting.
//  Interrupt line of the GPIO expander is wired in, so interrupt capability can be added in firmware if needed.
////////
#include <stdlib.h>
#include "esp_log.h"
#include "freertos/FreeRTOS.h"
#include "freertos/task.h"
#include "tinyusb.h"
#include "class/hid/hid_device.h"
#include "driver/gpio.h"
#include <pcf8575.h>

// I²C lines for GPIO Expander
#define PIN_I2C_SDA (GPIO_NUM_7)
#define PIN_I2C_SCL (GPIO_NUM_8)
#define PIN_I2C_INT (GPIO_NUM_9)
#define I2C_ADDR 0x20 //7-bit address of GPIO Expander
// MCU inputs
#define MOMENTARY_1A  (GPIO_NUM_1)
#define MOMENTARY_1B  (GPIO_NUM_2)
#define MOMENTARY_2A  (GPIO_NUM_42)
#define MOMENTARY_2B  (GPIO_NUM_41)
#define MOMENTARY_3A  (GPIO_NUM_40)
#define MOMENTARY_3B  (GPIO_NUM_39)
#define MOMENTARY_4A  (GPIO_NUM_48)
#define MOMENTARY_4B  (GPIO_NUM_47)
#define MOMENTARY_5A  (GPIO_NUM_21)
#define MOMENTARY_5B  (GPIO_NUM_14)
#define MOMENTARY_6A  (GPIO_NUM_13)
#define MOMENTARY_6B  (GPIO_NUM_12)
#define MOMENTARY_7A  (GPIO_NUM_11)
#define MOMENTARY_7B  (GPIO_NUM_10)
#define MOMENTARY_8A  (GPIO_NUM_18)
#define MOMENTARY_8B  (GPIO_NUM_17)
#define MOMENTARY_9A  (GPIO_NUM_16)
#define MOMENTARY_9B  (GPIO_NUM_15)
#define PUSHBUTTON    (GPIO_NUM_38)

#define GPIO_INPUT_MASK ((1ULL<<MOMENTARY_1A)|(1ULL<<MOMENTARY_1B)|(1ULL<<MOMENTARY_2A)|(1ULL<<MOMENTARY_2B)|(1ULL<<MOMENTARY_3A)|(1ULL<<MOMENTARY_3B)|(1ULL<<MOMENTARY_4A)|(1ULL<<MOMENTARY_4B)|(1ULL<<MOMENTARY_5A)|(1ULL<<MOMENTARY_5B)|(1ULL<<MOMENTARY_6A)|(1ULL<<MOMENTARY_6B)|(1ULL<<MOMENTARY_7A)|(1ULL<<MOMENTARY_7B)|(1ULL<<MOMENTARY_8A)|(1ULL<<MOMENTARY_8B)|(1ULL<<MOMENTARY_9A)|(1ULL<<MOMENTARY_9B)|(1ULL<<PUSHBUTTON))

static const char *TAG = "example";

/************* TinyUSB descriptors ****************/

#define TUSB_DESC_TOTAL_LEN      (TUD_CONFIG_DESC_LEN + CFG_TUD_HID * TUD_HID_DESC_LEN)

/**
 * @brief HID report descriptor
 *
 */
const uint8_t hid_report_descriptor[] = {
    TUD_HID_REPORT_DESC_GAMEPAD()
};

/**
 * @brief String descriptor
 */
const char* hid_string_descriptor[5] = {
    // array of pointer to string descriptors
    (char[]){0x09, 0x04},  // 0: is supported language is English (0x0409)
    "TinyUSB",             // 1: Manufacturer
    "Sim Button Box",      // 2: Product
    "123456",              // 3: Serials, should use chip ID
    "Example HID interface",  // 4: HID
};

/**
 * @brief Configuration descriptor
 *
 * This is a simple configuration descriptor that defines 1 configuration and 1 HID interface
 */
static const uint8_t hid_configuration_descriptor[] = {
    // Configuration number, interface count, string index, total length, attribute, power in mA
    TUD_CONFIG_DESCRIPTOR(1, 1, 0, TUSB_DESC_TOTAL_LEN, TUSB_DESC_CONFIG_ATT_REMOTE_WAKEUP, 100),

    // Interface number, string index, boot protocol, report descriptor len, EP In address, size & polling interval
    TUD_HID_DESCRIPTOR(0, 4, false, sizeof(hid_report_descriptor), 0x81, 16, 10),
};

/**
 * @brief Gamepad report
 */
static hid_gamepad_report_t gamepad_report;

/********* TinyUSB HID callbacks ***************/

// Invoked when received GET HID REPORT DESCRIPTOR request
// Application return pointer to descriptor, whose contents must exist long enough for transfer to complete
uint8_t const *tud_hid_descriptor_report_cb(uint8_t instance)
{
    // We use only one interface and one HID report descriptor, so we can ignore parameter 'instance'
    return hid_report_descriptor;
}

// Invoked when received GET_REPORT control request
// Application must fill buffer report's content and return its length.
// Return zero will cause the stack to STALL request
uint16_t tud_hid_get_report_cb(uint8_t instance, uint8_t report_id, hid_report_type_t report_type, uint8_t* buffer, uint16_t reqlen)
{
    (void) instance;
    (void) report_id;
    (void) report_type;
    (void) buffer;
    (void) reqlen;

    return 0;
}

// Invoked when received SET_REPORT control request or
// received data on OUT endpoint ( Report ID = 0, Type = 0 )
void tud_hid_set_report_cb(uint8_t instance, uint8_t report_id, hid_report_type_t report_type, uint8_t const* buffer, uint16_t bufsize)
{
}

/********* Application ***************/

// Copy contents of gamepad report struct.
static void copy_gamepad_report(hid_gamepad_report_t* source, hid_gamepad_report_t* destination)
{
    destination->x = source->x;
    destination->y = source->y;
    destination->z = source->z;
    destination->rz = source->rz;
    destination->rx = source->rx;
    destination->ry = source->ry;
    destination->hat = source->hat;
    destination->buttons = source->buttons;
}

// Compare contents of gamepad report struct. Return True if contents differ, so we don't send the same report repeatedly
static bool compare_gamepad_report(hid_gamepad_report_t* rep_a, hid_gamepad_report_t* rep_b)
{
    uint8_t count = 0;
    count += rep_a->x != rep_b->x;
    count += rep_a->y != rep_b->y;
    count += rep_a->z != rep_b->z;
    count += rep_a->rz != rep_b->rz;
    count += rep_a->rx != rep_b->rx;
    count += rep_a->ry != rep_b->ry;
    count += rep_a->hat != rep_b->hat;
    count += rep_a->buttons != rep_b->buttons;
    if(count > 0) return true;
    else return false;
}

static void app_send_hid_demo(hid_gamepad_report_t report)
{
    // Gamepad output
    ESP_LOGI(TAG, "Sending Gamepad report");
    tud_hid_report(0, &report, sizeof(report));
    vTaskDelay(pdMS_TO_TICKS(1));
}

void app_main(void)
{
    // Initialize buttons
    const gpio_config_t button_config = {
        .pin_bit_mask = GPIO_INPUT_MASK,
        .mode = GPIO_MODE_INPUT,
        .intr_type = GPIO_INTR_DISABLE,
        // Pullups are external, so no need to enable the internal ones
        .pull_up_en = false,
        .pull_down_en = false,
    };
    ESP_ERROR_CHECK(gpio_config(&button_config));

    // Initialize IO expander
    ESP_ERROR_CHECK(i2cdev_init());
    i2c_dev_t pcf8575;
    memset(&pcf8575, 0, sizeof(i2c_dev_t));
    ESP_ERROR_CHECK(pcf8575_init_desc(&pcf8575, I2C_ADDR, 0, PIN_I2C_SDA, PIN_I2C_SCL));
    uint16_t gpioExpanderPortVal = 0xFFFF;

    ESP_LOGI(TAG, "USB initialization");
    const tinyusb_config_t tusb_cfg = {
        .device_descriptor = NULL,
        .string_descriptor = hid_string_descriptor,
        .string_descriptor_count = sizeof(hid_string_descriptor) / sizeof(hid_string_descriptor[0]),
        .external_phy = false,
#if (TUD_OPT_HIGH_SPEED)
        .fs_configuration_descriptor = hid_configuration_descriptor, // HID configuration descriptor for full-speed and high-speed are the same
        .hs_configuration_descriptor = hid_configuration_descriptor,
        .qualifier_descriptor = NULL,
#else
        .configuration_descriptor = hid_configuration_descriptor,
#endif // TUD_OPT_HIGH_SPEED
    };

    ESP_ERROR_CHECK(tinyusb_driver_install(&tusb_cfg));
    ESP_LOGI(TAG, "USB initialization DONE");

    // Initialize gamepad state to all 0
    gamepad_report.x = 0;
    gamepad_report.y = 0;
    gamepad_report.z = 0;
    gamepad_report.rz = 0;
    gamepad_report.rx = 0;
    gamepad_report.ry = 0;
    gamepad_report.hat = 0;
    gamepad_report.buttons = 0;
    static hid_gamepad_report_t prevgamepad_report;
    copy_gamepad_report(&gamepad_report, &prevgamepad_report);

    // Main program loop
    while (1) {
        if (tud_mounted()) {
            // If the new report differs form the previous one, send it through USB.
            if(compare_gamepad_report(&gamepad_report, &prevgamepad_report)) {
                copy_gamepad_report(&gamepad_report, &prevgamepad_report);
                app_send_hid_demo(gamepad_report);
            }
            // Get IO states and build report
            gamepad_report.buttons = 0;
            if(!gpio_get_level(MOMENTARY_1A)){
                gamepad_report.buttons += GAMEPAD_BUTTON_0;
            } if(!gpio_get_level(MOMENTARY_1B)){
                gamepad_report.buttons += GAMEPAD_BUTTON_1;
            } if(!gpio_get_level(MOMENTARY_2A)){
                gamepad_report.buttons += GAMEPAD_BUTTON_2;
            } if(!gpio_get_level(MOMENTARY_2B)){
                gamepad_report.buttons += GAMEPAD_BUTTON_3;
            } if(!gpio_get_level(MOMENTARY_3A)){
                gamepad_report.buttons += GAMEPAD_BUTTON_4;
            } if(!gpio_get_level(MOMENTARY_3B)){
                gamepad_report.buttons += GAMEPAD_BUTTON_5;
            } if(!gpio_get_level(MOMENTARY_4A)){
                gamepad_report.buttons += GAMEPAD_BUTTON_6;
            } if(!gpio_get_level(MOMENTARY_4B)){
                gamepad_report.buttons += GAMEPAD_BUTTON_7;
            } if(!gpio_get_level(MOMENTARY_5A)){
                gamepad_report.buttons += GAMEPAD_BUTTON_8;
            } if(!gpio_get_level(MOMENTARY_5B)){
                gamepad_report.buttons += GAMEPAD_BUTTON_9;
            } if(!gpio_get_level(MOMENTARY_6A)){
                gamepad_report.buttons += GAMEPAD_BUTTON_10;
            } if(!gpio_get_level(MOMENTARY_6B)){
                gamepad_report.buttons += GAMEPAD_BUTTON_11;
            } if(!gpio_get_level(MOMENTARY_7A)){
                gamepad_report.buttons += GAMEPAD_BUTTON_12;
            } if(!gpio_get_level(MOMENTARY_7B)){
                gamepad_report.buttons += GAMEPAD_BUTTON_13;
            } if(!gpio_get_level(MOMENTARY_8A)){
                gamepad_report.buttons += GAMEPAD_BUTTON_14;
            } if(!gpio_get_level(MOMENTARY_8B)){
                gamepad_report.buttons += GAMEPAD_BUTTON_15;
            } if(!gpio_get_level(MOMENTARY_9A)){
                gamepad_report.buttons += GAMEPAD_BUTTON_16;
            } if(!gpio_get_level(MOMENTARY_9B)){
                gamepad_report.buttons += GAMEPAD_BUTTON_17;
            } if(!gpio_get_level(PUSHBUTTON)){
                gamepad_report.buttons += GAMEPAD_BUTTON_18;
            }
            // Poll GPIO Expander and complete report
            pcf8575_port_read(&pcf8575, &gpioExpanderPortVal);
            ESP_LOGI("IOEXP","Port read : %d", gpioExpanderPortVal);
            gamepad_report.buttons += (((uint32_t)gpioExpanderPortVal & 0x000000FF) << 24);
        }
        // Some dead time to allow other OS tasks to run, like the USB stack
        vTaskDelay(pdMS_TO_TICKS(20));
    }
}

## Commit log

2025-12-30 GAmepad reported OK with 1 button in polling mode
2026-03-22 Full (polling) implementation of PCB with IOexp
2026-03-22 Fixed missing pushbutton definition
    [tusb_hid_example_main.c]
2026-09-01 Added hardware files and small README
    [1456CE3BKBU_Drilled.step, 3DPCB_ESP32_SimButtonBox_Controller.step, ASSEMBLED_Buttonbox.step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]

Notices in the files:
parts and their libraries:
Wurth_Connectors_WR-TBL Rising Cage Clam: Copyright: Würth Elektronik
